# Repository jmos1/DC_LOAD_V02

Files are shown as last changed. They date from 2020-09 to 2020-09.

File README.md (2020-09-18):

# DC_LOAD_V02
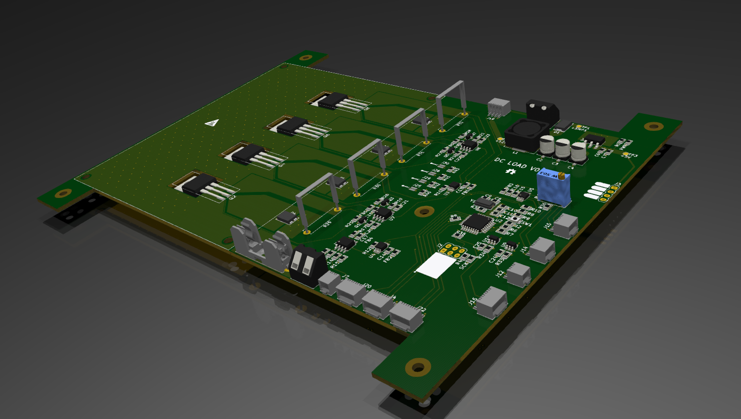
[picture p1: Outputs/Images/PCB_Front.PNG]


### Summary: ###
  This board is a follow up to the 1A DC_LOAD_V01 prototype. It is a 5A, 30V, 100W constant current load that will be mounted
  in a Jameco project enclosure. It currently isn't finished or tested yet, but feel free to have a look around anyway!
  
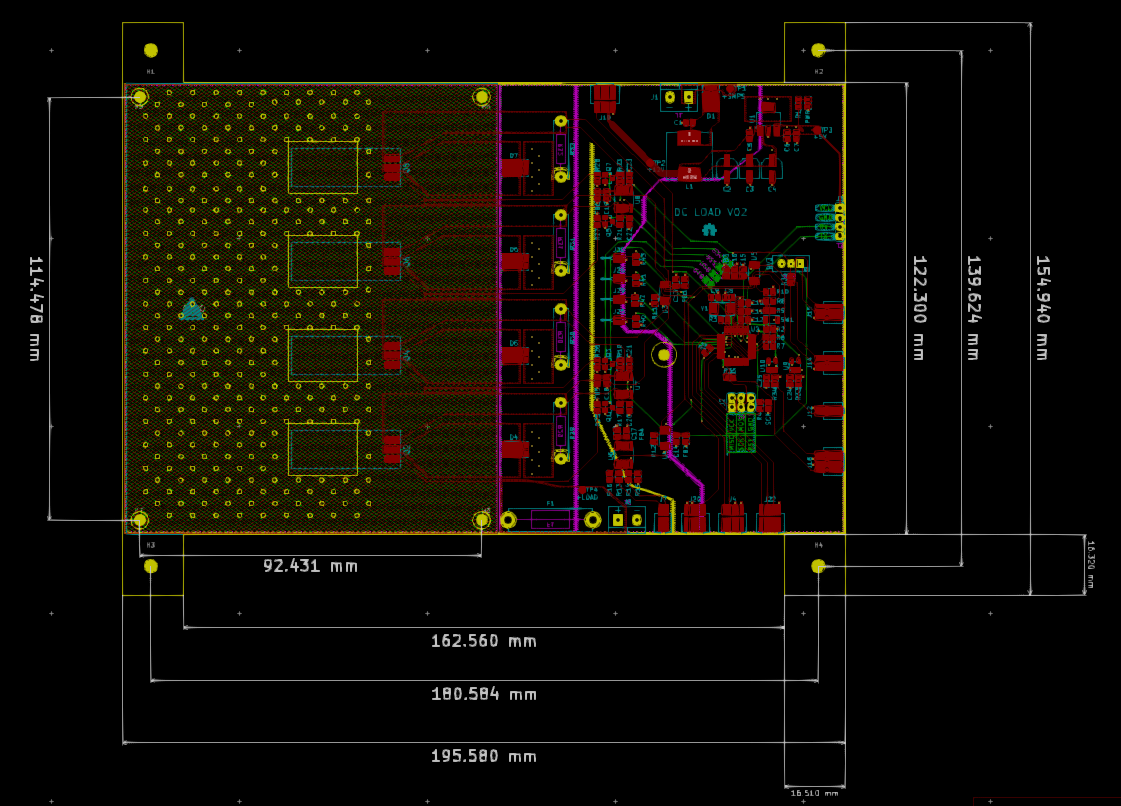
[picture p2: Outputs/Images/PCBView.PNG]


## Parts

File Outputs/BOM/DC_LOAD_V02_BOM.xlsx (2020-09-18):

Comment | MPN | Manufacturer | Part Number | Supplier | Quantity
IC INVERTER SCHMITT 1CH SOT23-5 | NC7S14M5X | ON Semiconductor | NC7S14M5XCT-ND | DigiKey | 2
IC ADC 16BIT SIGMA-DELTA 10VSSOP | ADS1115IDGSR | Texas Instruments | 296-38849-1-ND | DigiKey | 2
AC/DC CONVERTER 12V 16W | RS-15-12 | MEAN WELL USA Inc. | 1866-4128-ND | DigiKey | 1
IC OPAMP GP 2 CIRCUIT 8SOIC | LM358DR | Texas Instruments | 296-1014-1-ND | DigiKey | 2
TRANS NPN 40V 0.2A SOT23 | MMBT3904LT3G | ON Semiconductor | MMBT3904LT3GOSCT-ND | DigiKey | 4
FUSE CERM 5A 500VAC 400VDC 5X20 | 0477005.MXP | Littelfuse Inc. | F2990-ND | DigiKey | 1
IC DAC 12BIT V-OUT 10MSOP | MCP4728T-E/UN | Microchip Technology | MCP4728T-E/UNCT-ND | DigiKey | 1
PWR ENT MOD RCPT IEC320-C14 PNL | 1-1609112-1 | TE Connectivity Corcom Filters | CCM1914-ND | DigiKey | 1
FUSE BLOCK CART 250V 6.3A PCB | 3527 | Keystone Electronics | 36-3527-ND | DigiKey | 1
TERM BLK 2POS SIDE ENTRY 5MM PCB | 691137710002 | Würth Elektronik | 732-10955-ND | DigiKey | 2
IC REG LINEAR 5V 1.5A SOT223-4 | LM7805MPX/NOPB | Texas Instruments | 296-44518-1-ND | DigiKey | 1
MOSFET N-CH 55V 80A TO-220 | STP80NF55L-06 | STMicroelectronics | 497-5898-5-ND | DigiKey | 4
DIODE SCHOTTKY 100V 8A TO-277 | FSV8100V | ON Semiconductor | FSV8100VCT-ND | DigiKey | 5
THERMISTOR NTC 10KOHM 3380K BEAD | NXFT15XH103FA2B100 | Murata Electronics | 490-5630-ND | DigiKey | 4
IC OPAMP GP 2 CIRCUIT 8SOIC | LM6132BIMX/NOPB | Texas Instruments | LM6132BIMX/NOPB | DigiKey | 1
LED RED/YELLOW CLEAR 4SMD | APHB1608SYKSURKC | Kingbright | 754-1855-1-ND | DigiKey | 1
SWITCH ILLUMINATED PUSH | 54-701-R | NTE Electronics, Inc | 2368-54-701-R-ND | DigiKey | 1
SWITCH PUSH SPST-NO 3A 125V | PS1024ABLK | E-Switch | EG2011-ND | DigiKey | 1
BINDING POST BLACK 10 AMP | 81-BP6B | NTE Electronics, Inc | 2368-81-BP6B-ND | DigiKey | 1
BINDING POST RED 10 AMP | 81-BP6R | NTE Electronics, Inc | 2368-81-BP6R-ND | DigiKey | 1
FERRITE BEAD 300 OHM 0805 1LN | MI0805L301R-10 | Laird-Signal Integrity Products | 240-2391-1-ND | DigiKey | 6
CAP CER 10UF 25V X5R 0805 | GRM21BR61E106KA73K | Murata Electronics | 490-16824-1-ND | DigiKey | 6
CAP CER 1UF 50V X5R 0805 | GRM219R61H105KA73D | Murata Electronics | 490-10743-6-ND | DigiKey | 7
CAP CER 0.1UF 50V X7R 0805 | C0805C104M5RACTU | KEMET | 399-1169-1-ND | DigiKey | 5
CAP CER SMD 0805 .01UF X7R 5% 50 | C0805C103J5RAC7210 | KEMET | 399-17616-1-ND | DigiKey | 2
SWITCH TACTILE SPST-NO 0.02A 15V | EVP-AWED2A | Panasonic Electronic Components | P19745CT-ND | DigiKey | 1
LED GREEN CLEAR CHIP SMD | LTST-C171GKT | Lite-On Inc. | 160-1423-1-ND | DigiKey | 1
LED YELLOW CLEAR CHIP SMD | LTST-C171KSKT | Lite-On Inc. | 160-1428-1-ND | DigiKey | 1
RES 0.1 OHM 3W 1% RADIAL | MSR3-0R1F1 | Riedon | 696-1648-ND | DigiKey | 4
FIXED IND 100UH 1.6A 165 MOHM | 49101SC | Murata Power Solutions Inc. | 811-3615-1-ND | DigiKey | 1
CAP ALUM 22UF 20% 35V SMD | EEE-FK1V220R | Panasonic Electronic Components | PCE3838CT-ND | DigiKey | 3
CONN HEADER SMD R/A 2POS 1.5MM | 874380243 | Molex | WM7646CT-ND | DigiKey | 2
CONN HOUSING 2POS 1.5MM W/RAMP | 874390200 | Molex | WM2086-ND | DigiKey | 2
CONN HEADER SMD R/A 3POS 1.5MM | 874380343 | Molex | WM7647CT-ND | DigiKey | 2
CONN HOUSING 3POS 1.5MM W/RAMP | 874390300 | Molex | WM2087-ND | DigiKey | 2
CONN HEADER SMD R/A 4POS 1.5MM | 874380443 | Molex | WM7648CT-ND | DigiKey | 5
CONN HOUSING 4POS 1.5MM W/RAMP | 874390400 | Molex | WM2088-ND | DigiKey | 5
CRYSTAL 16.0000MHZ 18PF SMD | ABM7-16.000MHZ-D2Y-T | Abracon LLC | 535-9840-1-ND | DigiKey | 1
CAP CER 18PF 50V C0G/NP0 0805 | C0805C180K5GACTU | KEMET | 399-8030-1-ND | DigiKey | 2
RES 0 OHM JUMPER 1/8W 0805 | RMCF0805ZT0R00 | Stackpole Electronics Inc | RMCF0805ZT0R00CT-ND | DigiKey | 4
RES SMD 1M OHM 1% 1/8W 0805 | RC0805FR-071ML | Yageo | 311-1.00MCRCT-ND | DigiKey | 1
RES 1K OHM 1% 1/4W 0805 | RNCP0805FTD1K00 | Stackpole Electronics Inc | RNCP0805FTD1K00CT-ND | DigiKey | 19
RES SMD 10K OHM 1% 1/8W 0805 | RC0805FR-0710KL | Yageo | 311-10.0KCRCT-ND | DigiKey | 13
RES 100K OHM 0.05% 1/8W 0805 | ERA-6ARW104V | Panasonic Electronic Components | P100KBSCT-ND | DigiKey | 2
RES 10K OHM 0.05% 1/8W 0805 | ERA-6ARW103V | Panasonic Electronic Components | P10KBSCT-ND | DigiKey | 2
IC MCU 8BIT 32KB FLASH 32TQFP | ATMEGA328PB-AUR | Microchip Technology | ATMEGA328PB-AURCT-ND | DigiKey | 1

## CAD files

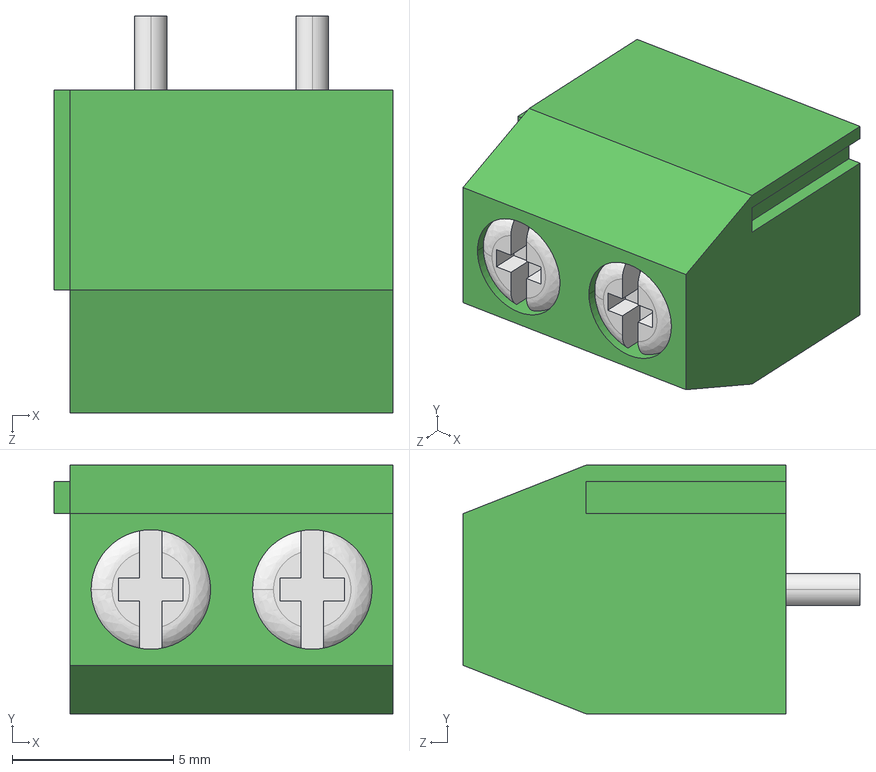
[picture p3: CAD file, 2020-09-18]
3D Models/TERM_BLK_1x2_691137710002.step
10.5 x 7.70 x 12.3 mm

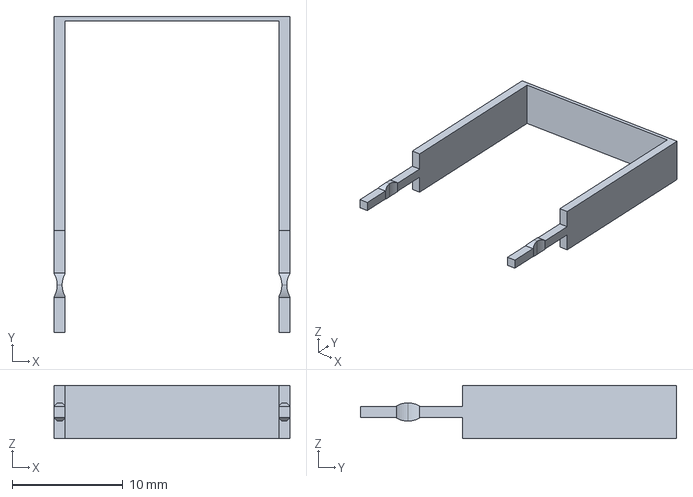
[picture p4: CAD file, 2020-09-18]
3D Models/RSHUNT_MSR3-0R1F1.stp
21.3 x 28.6 x 4.80 mm

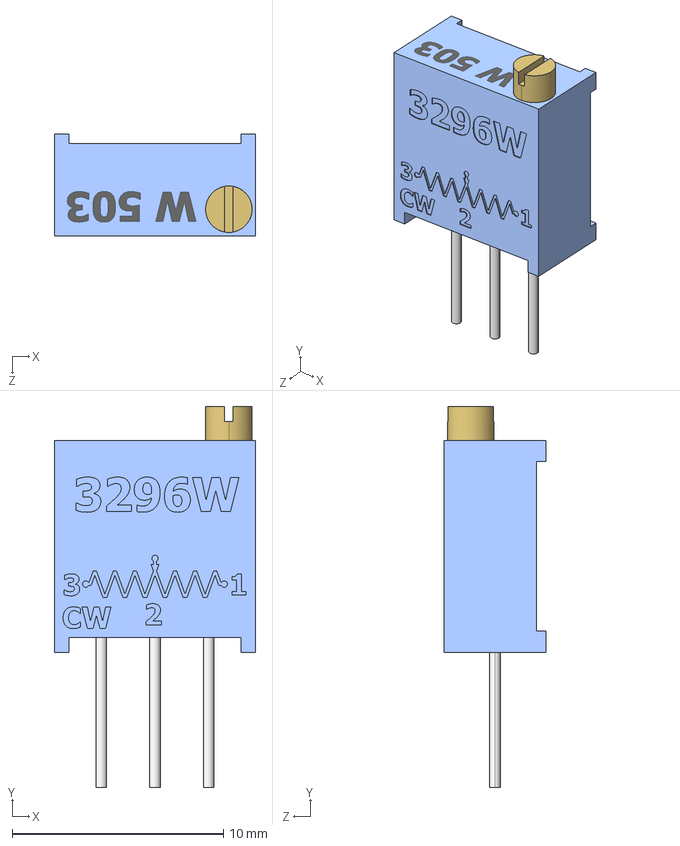
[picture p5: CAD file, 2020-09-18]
3D Models/TRIM_POT_50K.STEP
9.53 x 18.0 x 4.83 mm

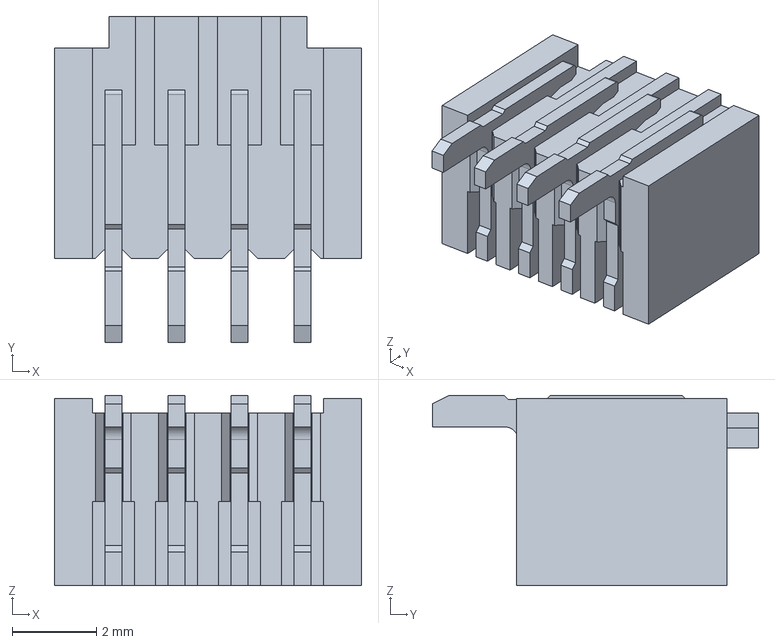
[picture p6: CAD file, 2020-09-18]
3D Models/MOLEX_1x4_CONN_0874380443.stp
7.30 x 7.75 x 4.52 mm

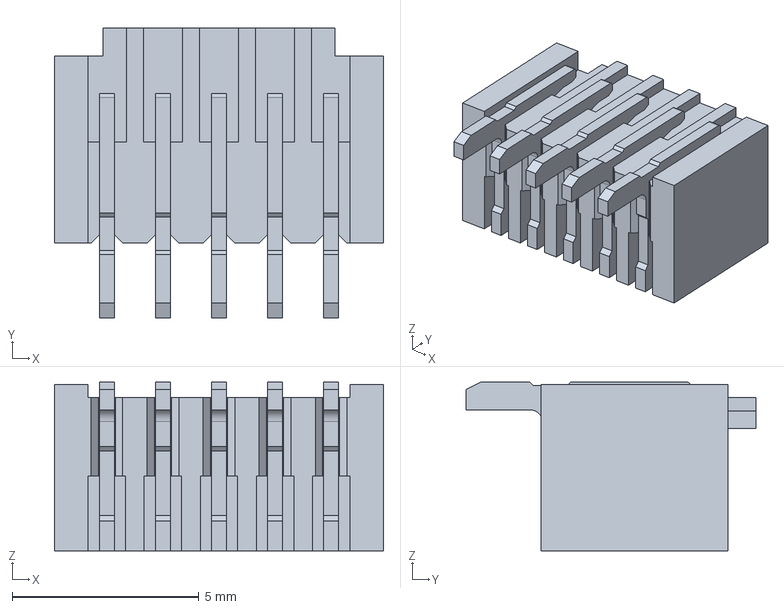
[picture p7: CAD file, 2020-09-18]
3D Models/MOLEX_1x5_CONN_874380543.stp
8.80 x 7.75 x 4.52 mm

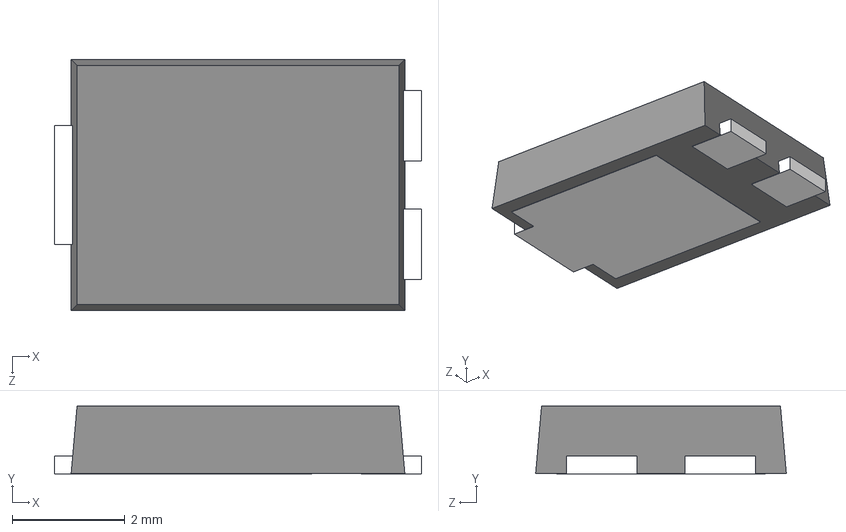
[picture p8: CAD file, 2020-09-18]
3D Models/POWER_DIODE_FSV12100V.STEP
6.50 x 1.20 x 4.44 mm

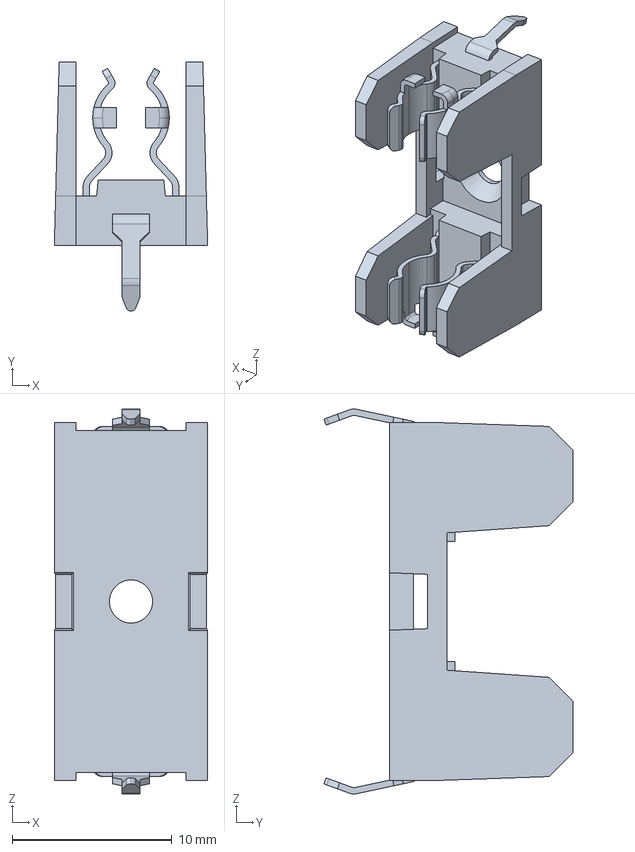
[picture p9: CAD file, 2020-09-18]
3D Models/FUSE_CLIP_3527.stp
9.60 x 15.6 x 24.1 mm

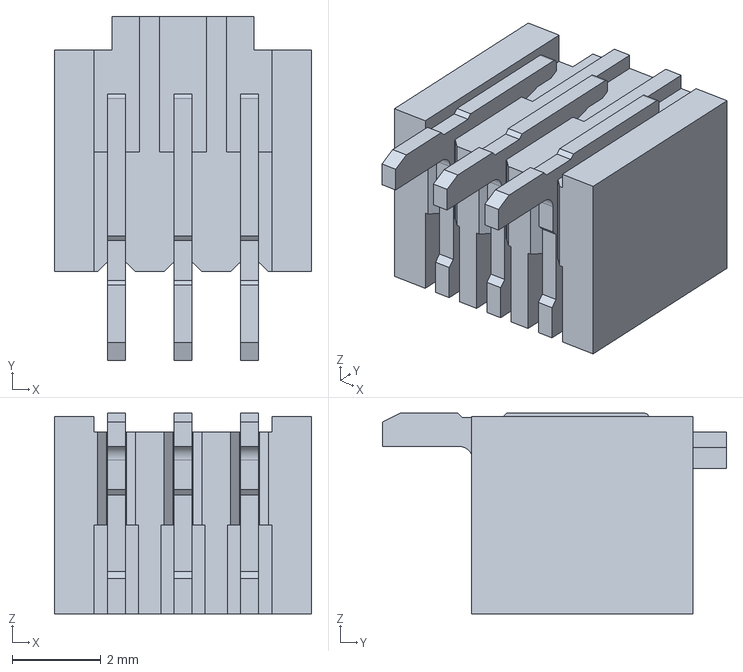
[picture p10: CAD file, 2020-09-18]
3D Models/MOLEX_1x3_CONN_874380343.stp
5.80 x 7.75 x 4.52 mm

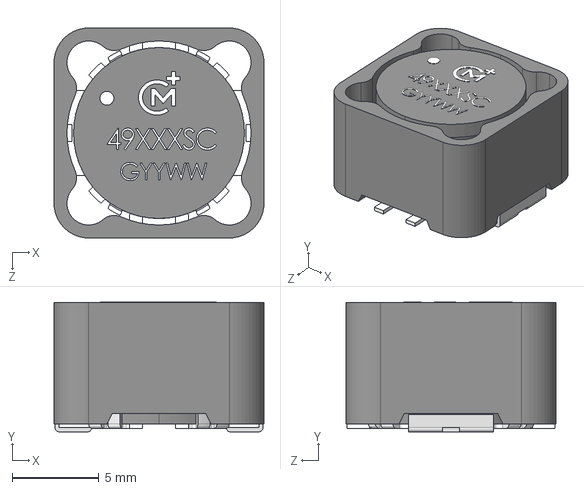
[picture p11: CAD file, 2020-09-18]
3D Models/INDUCTOR_100U_‎49101SC‎.STEP
12.1 x 7.47 x 12.1 mm

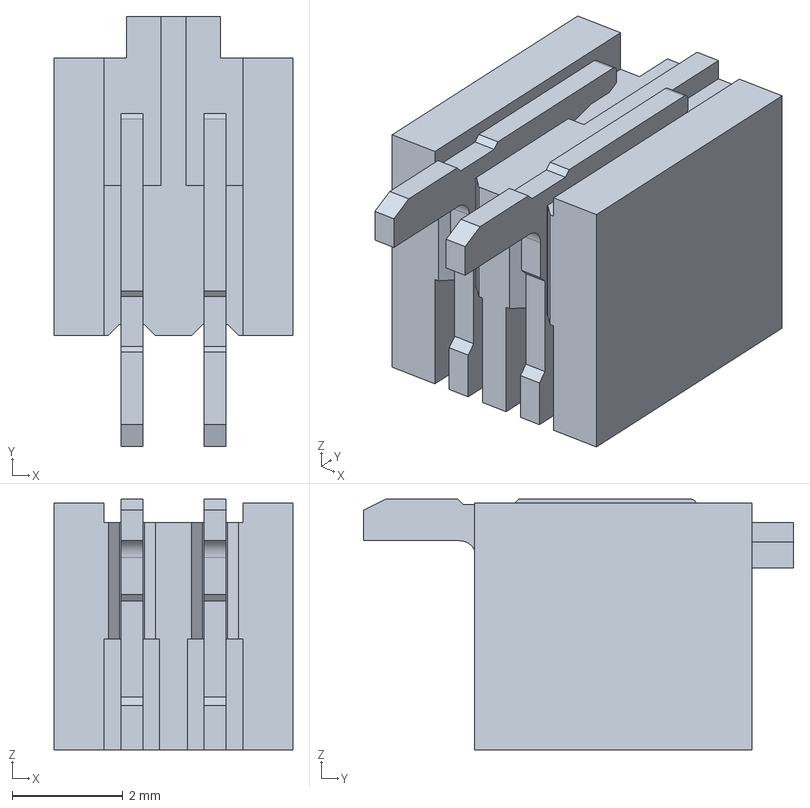
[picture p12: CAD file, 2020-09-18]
3D Models/MOLEX_1x2_CONN_874380243.stp
4.30 x 7.75 x 4.52 mm

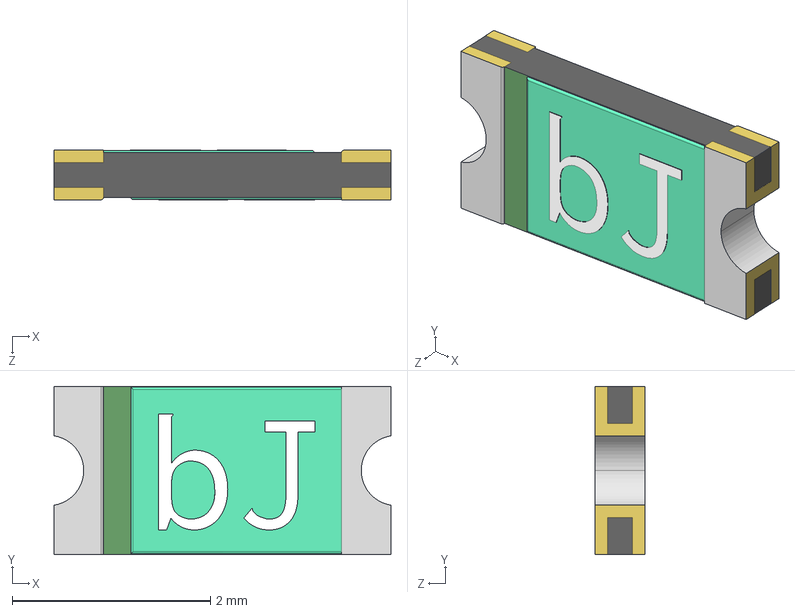
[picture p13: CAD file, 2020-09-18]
3D Models/FUSE_375MA_0466.375NR.STEP
3.40 x 1.70 x 0.508 mm

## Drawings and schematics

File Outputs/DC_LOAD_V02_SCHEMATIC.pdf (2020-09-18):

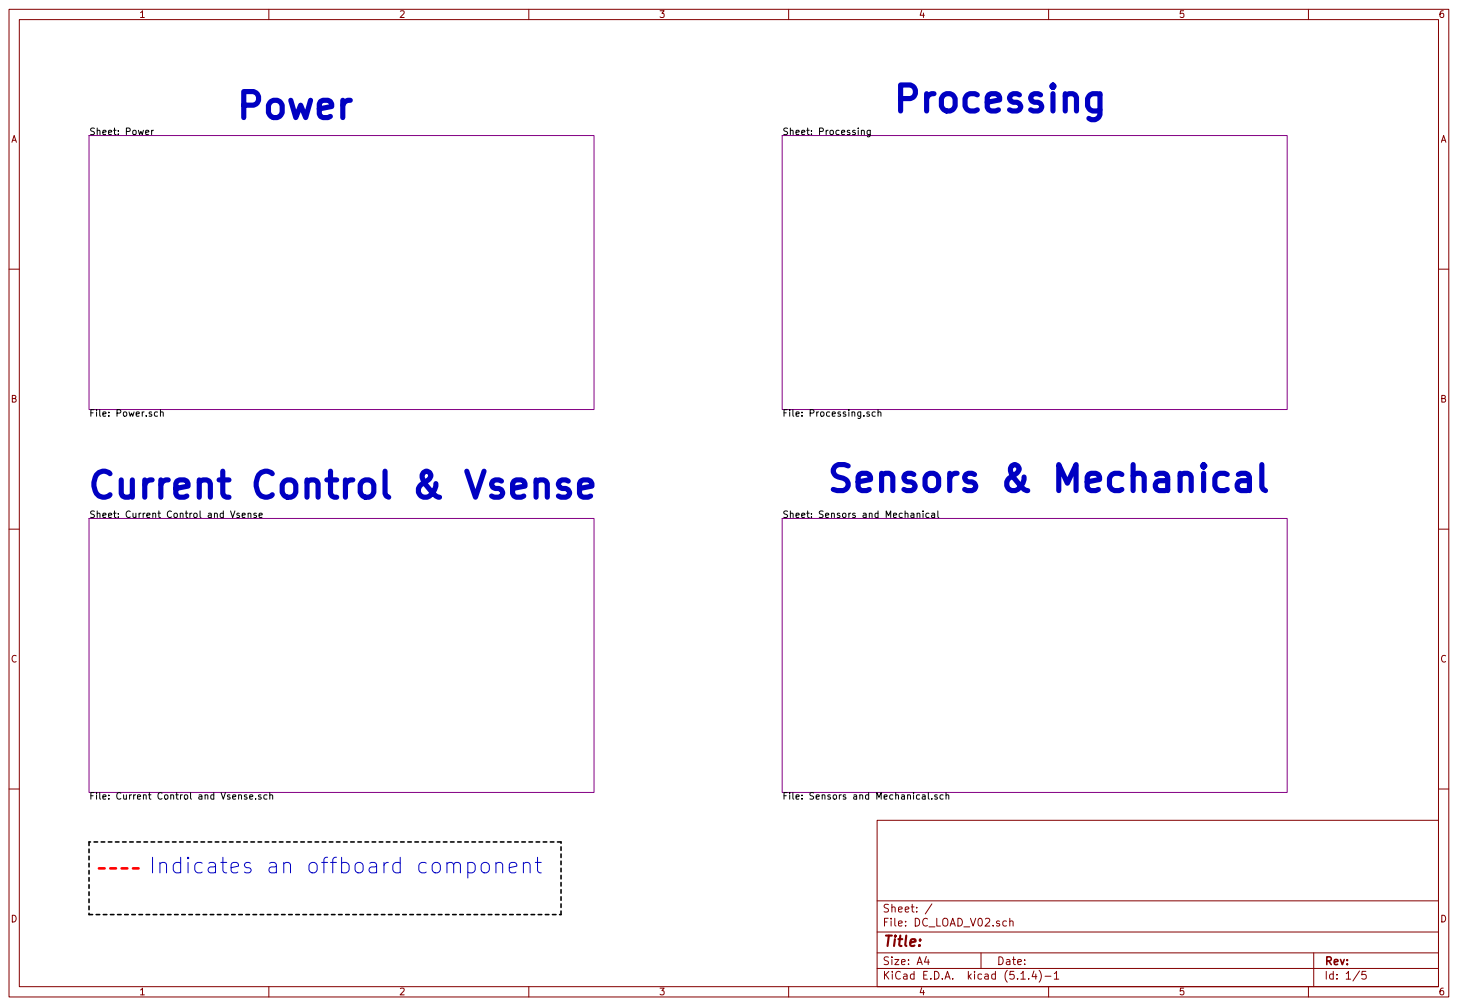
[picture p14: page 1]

Indicates an offboard component

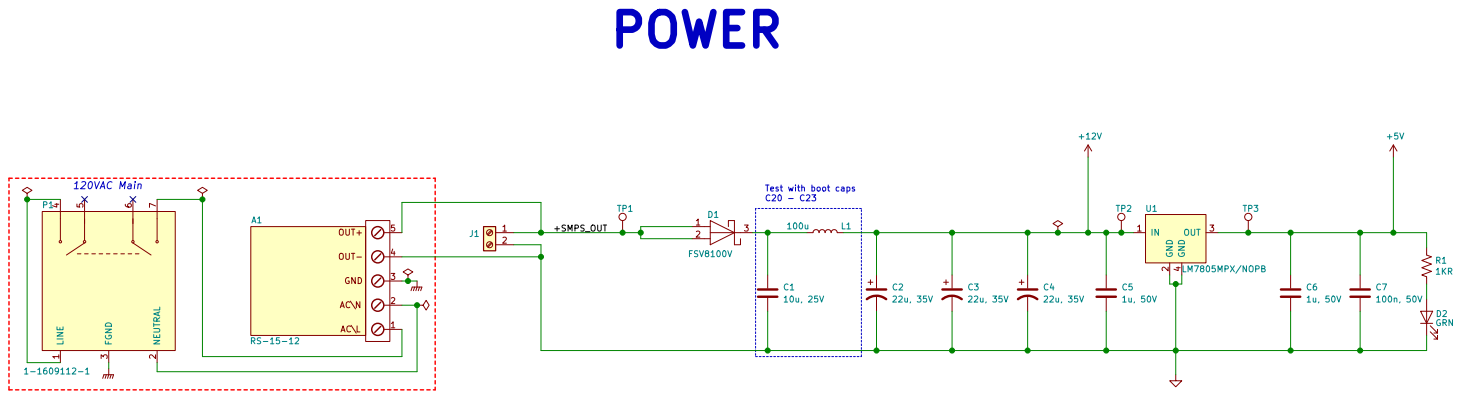
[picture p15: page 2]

Test with boot caps C20 - C23 POWER

AC\L GND OUT+ OUT- AC\N

Id: 2/5 Title: Power File: Power.sch Sheet: /Power/

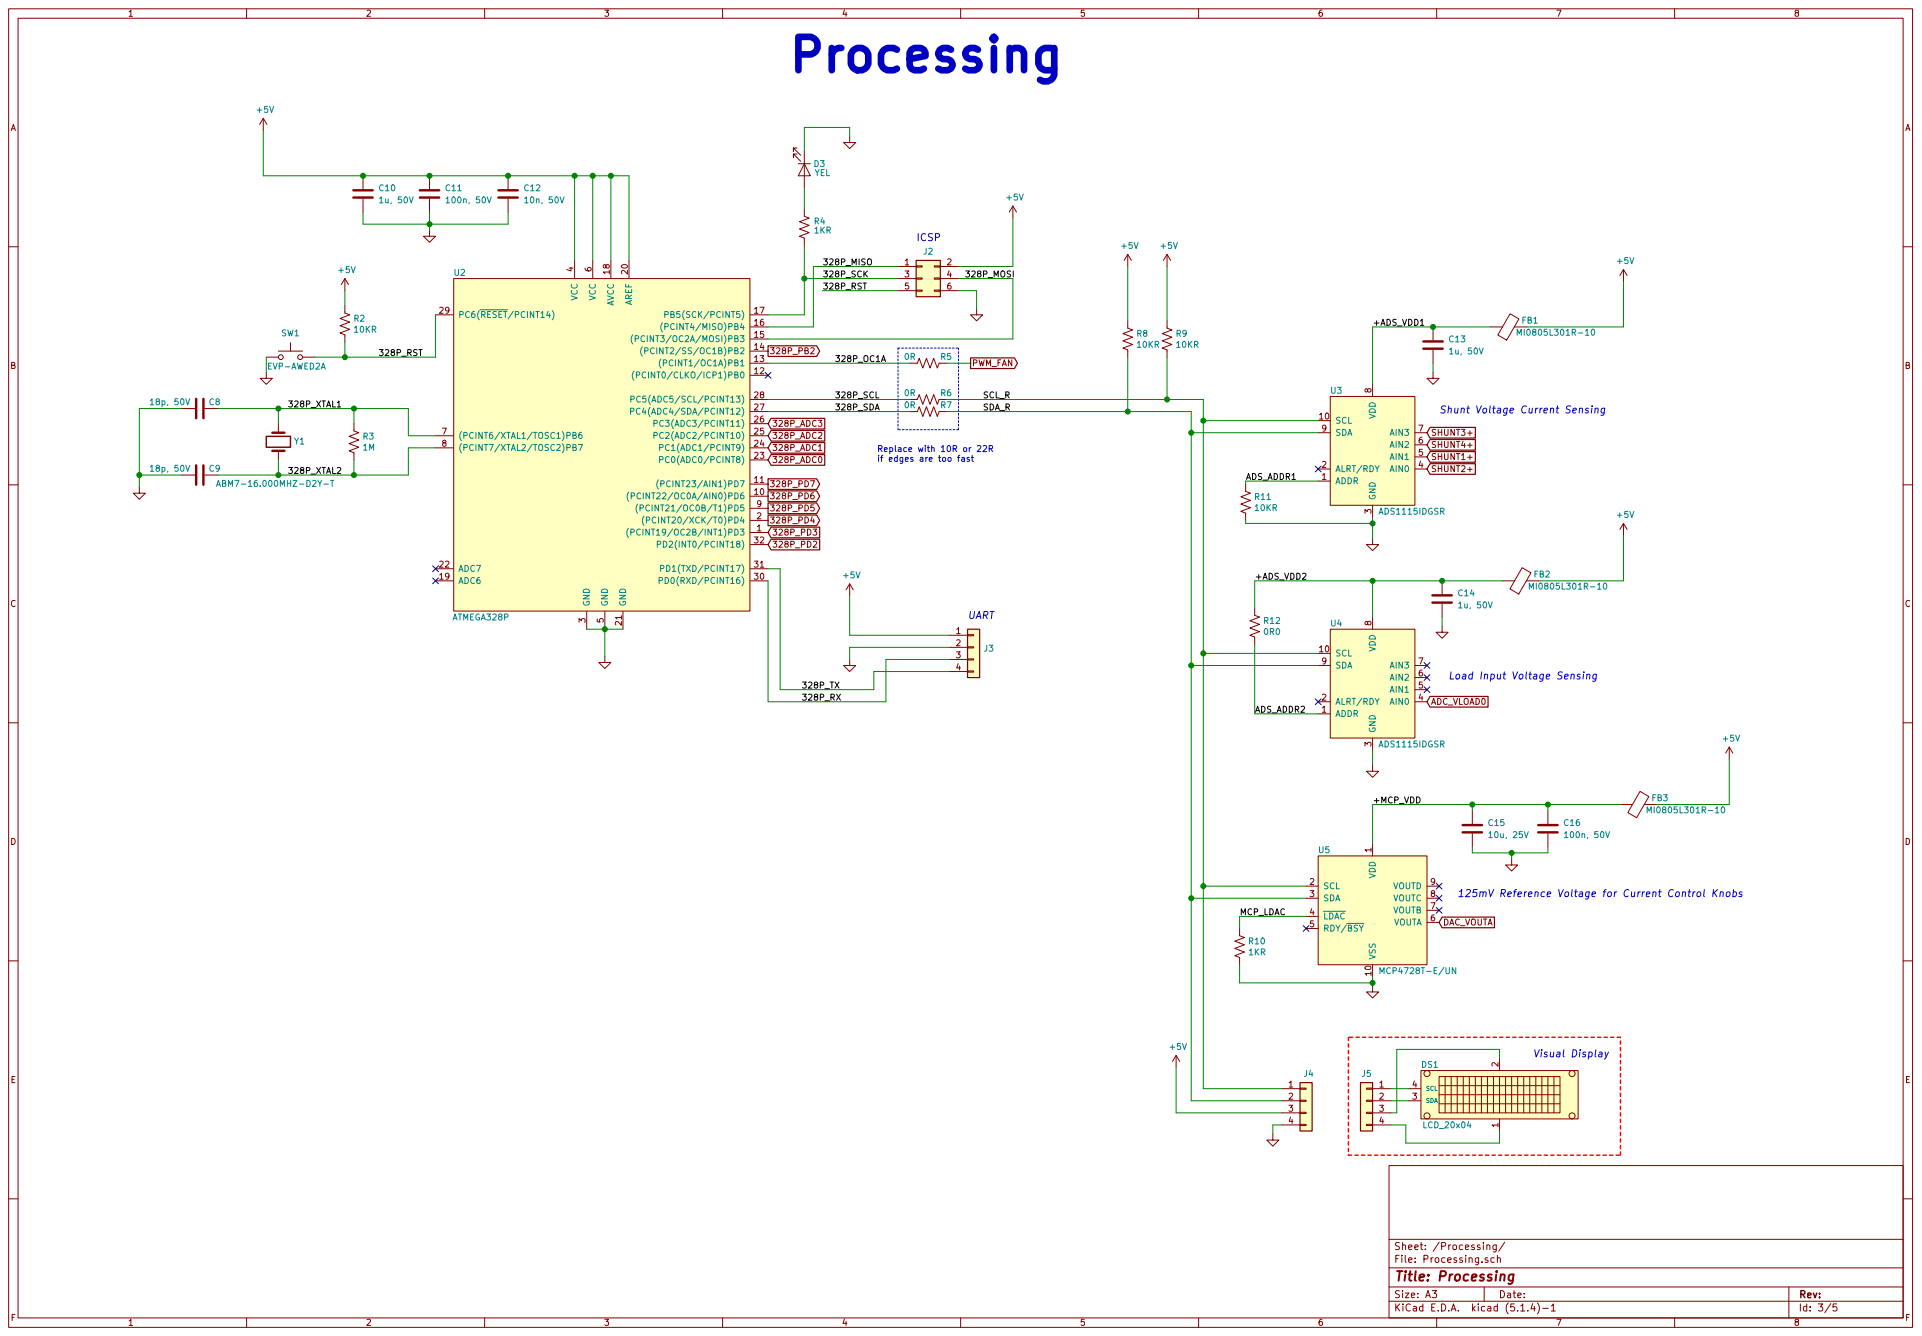
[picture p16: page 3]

Shunt Voltage Current Sensing

Replace with 10R or 22R
if edges are too fast

Load Input Voltage Sensing

125mV Reference Voltage for Current Control Knobs

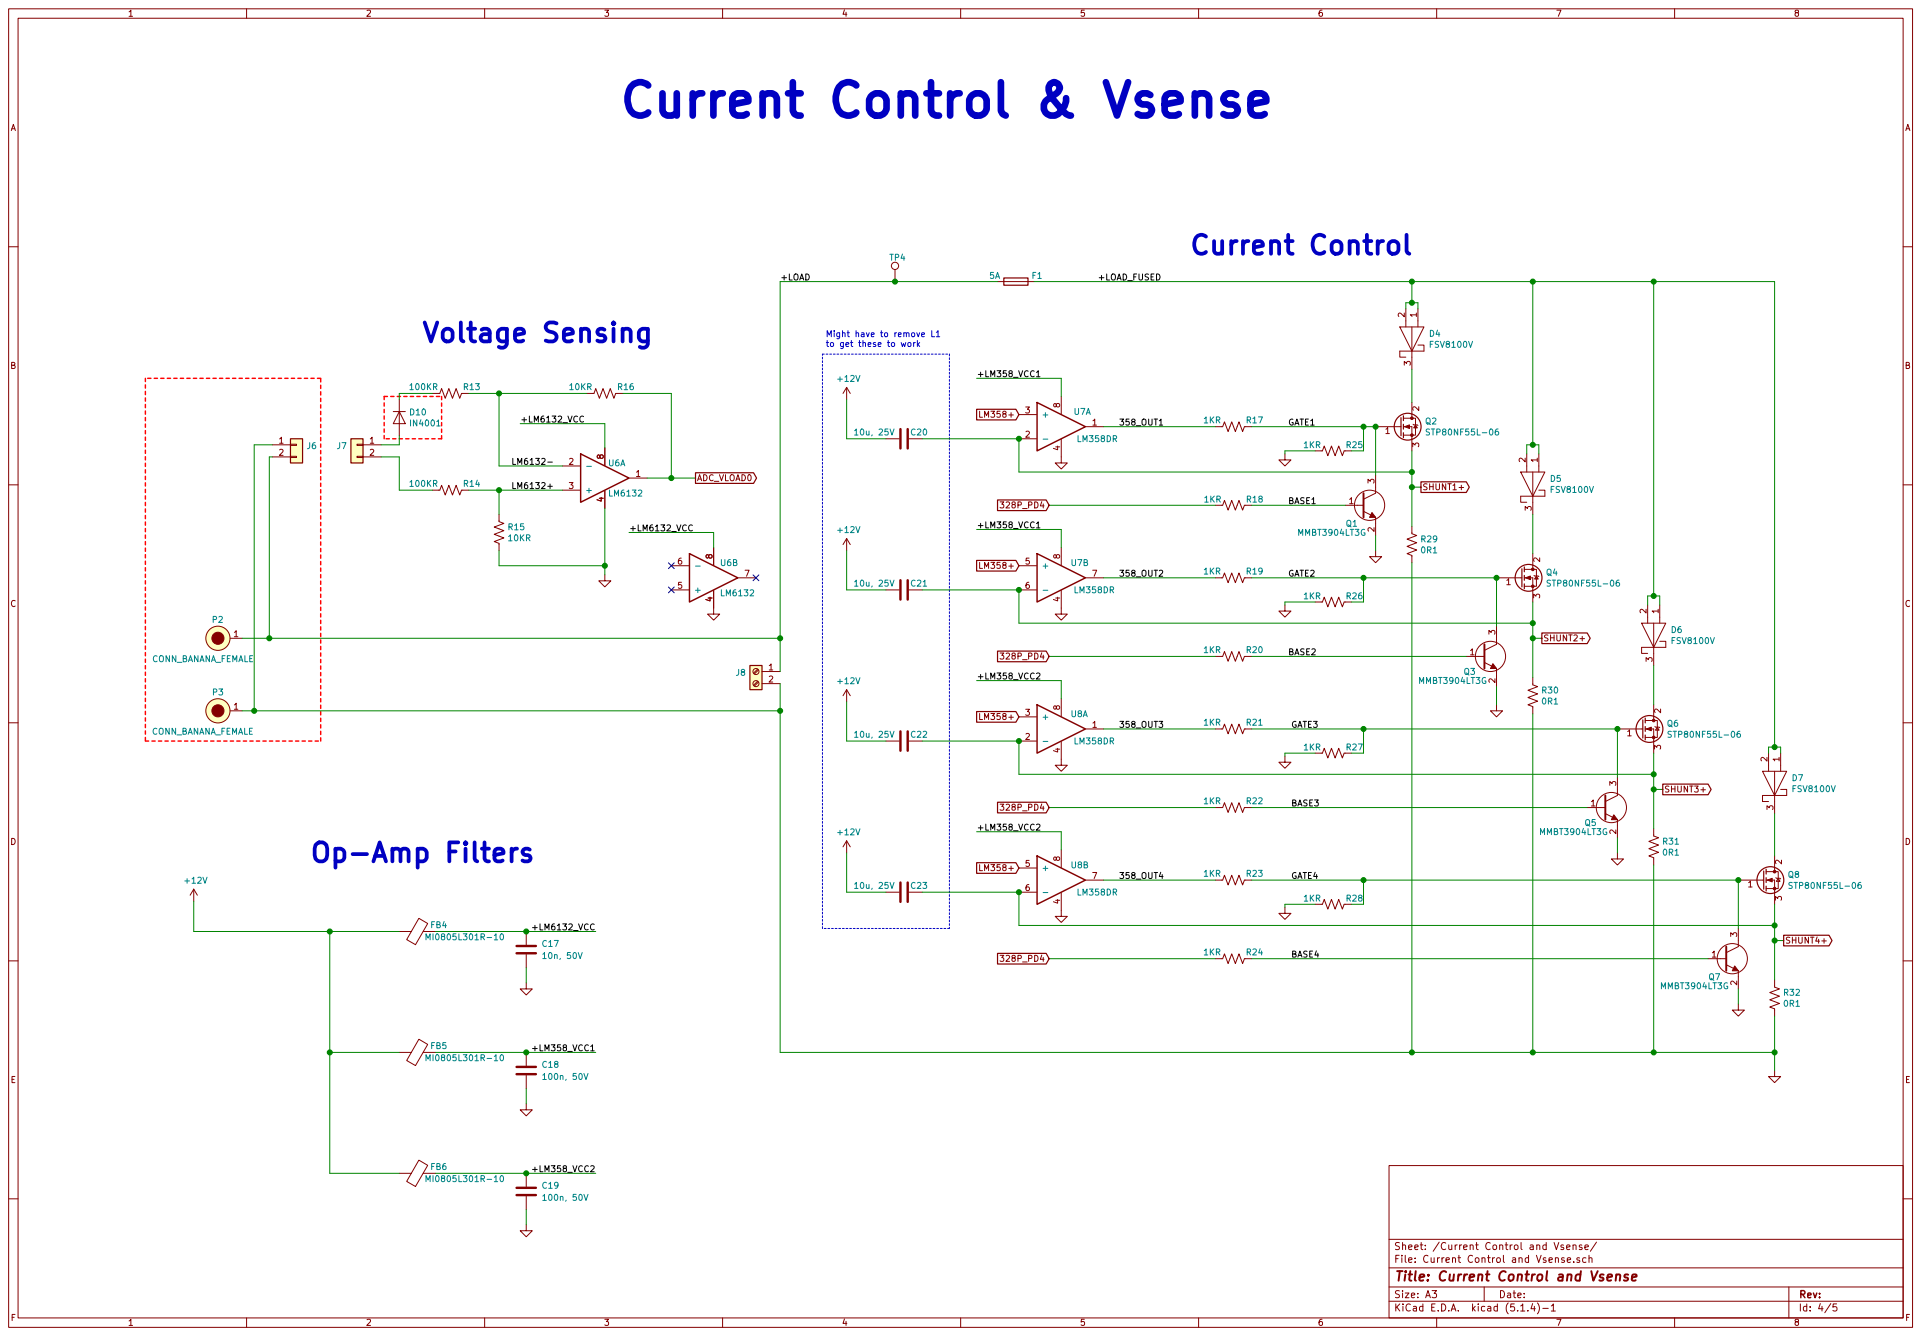
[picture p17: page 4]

Might have to remove L1
to get these to work

File: Current Control and Vsense.sch Sheet: /Current Control and Vsense/
Id: 4/5 Title: Current Control and Vsense

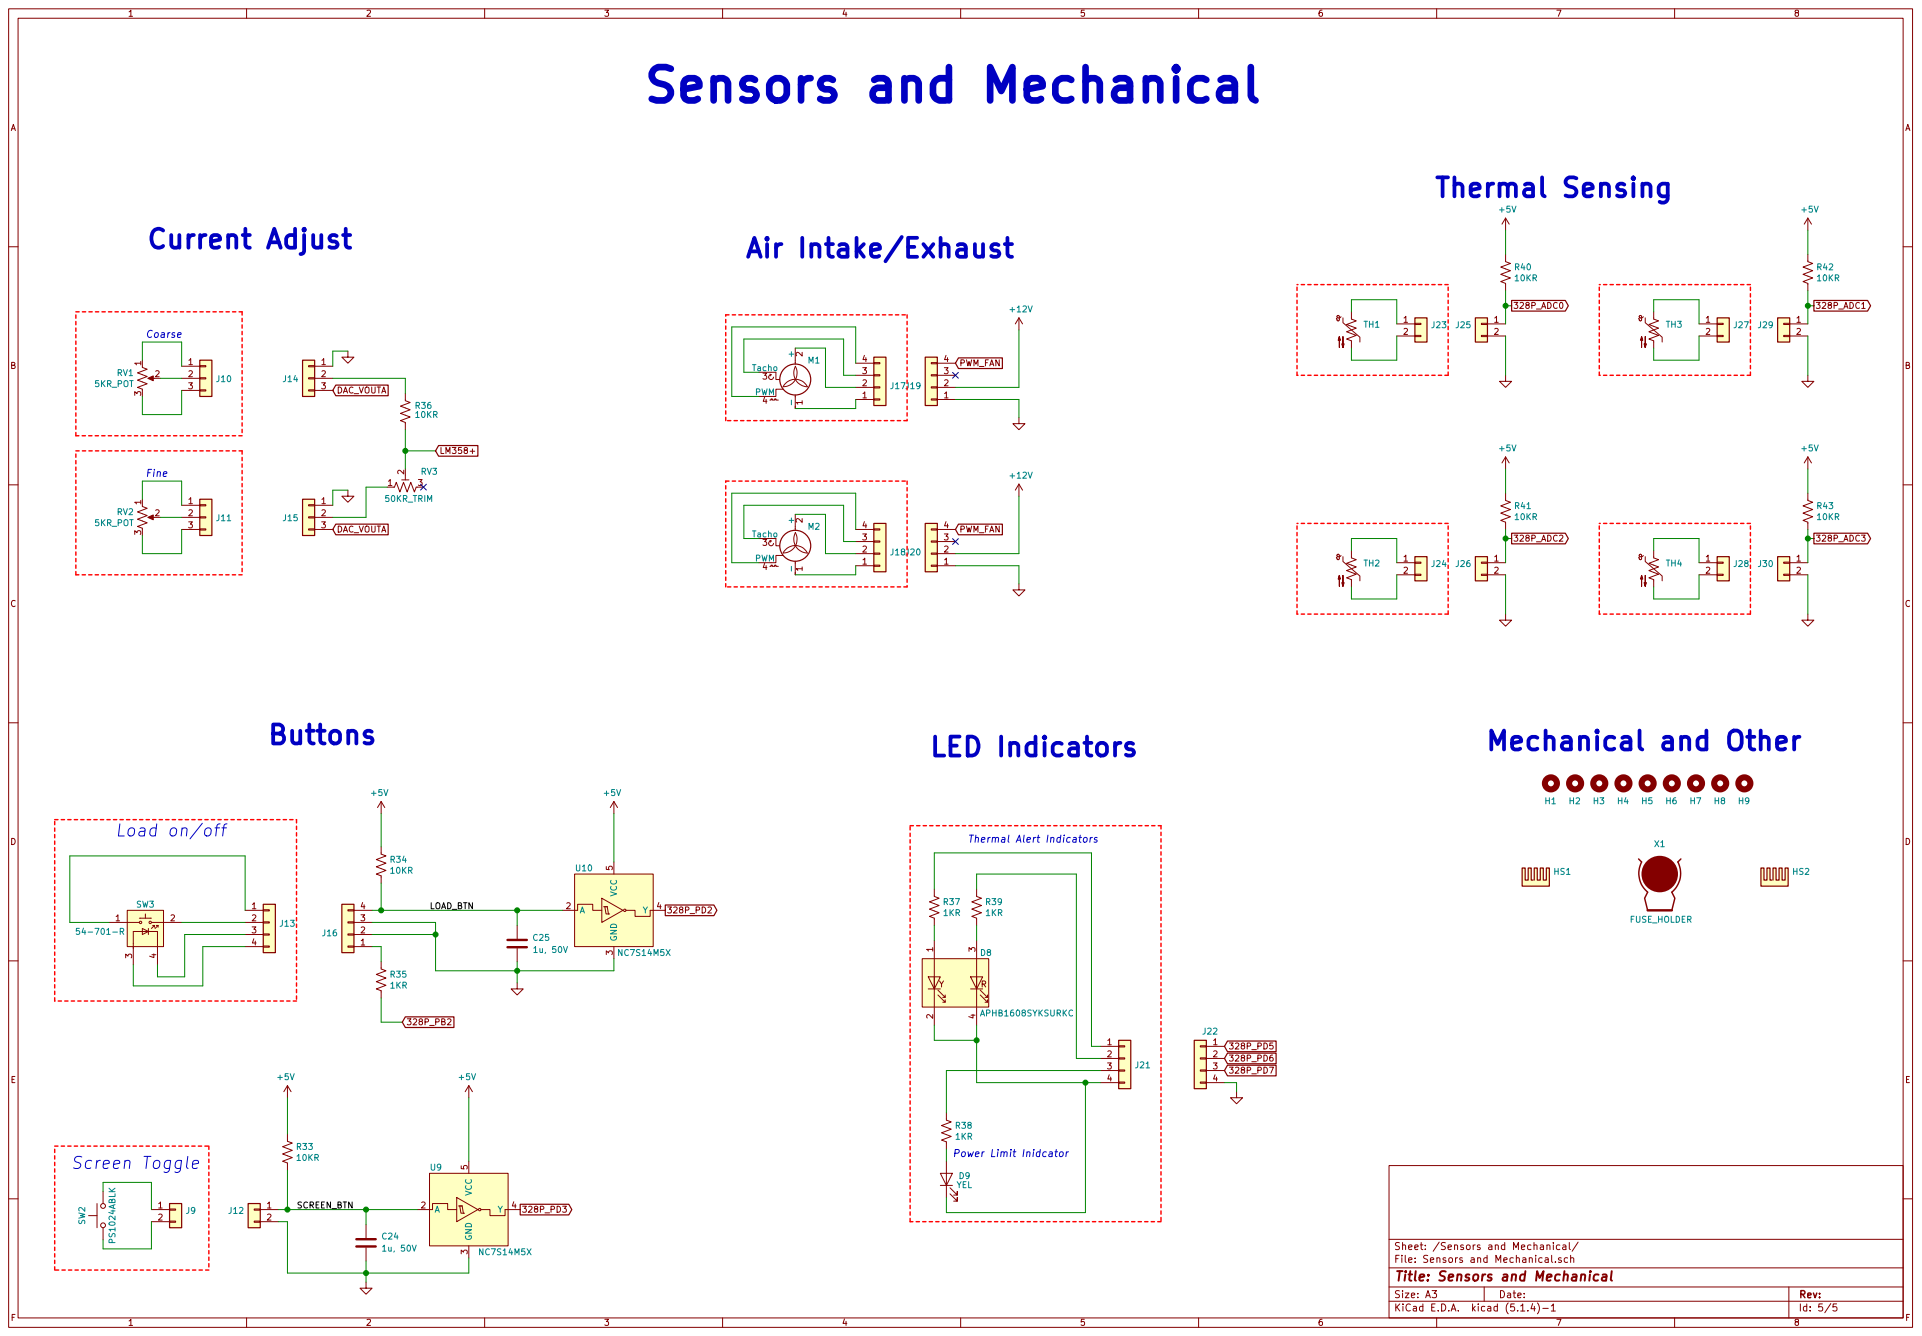
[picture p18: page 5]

Thermal Alert Indicators Screen Toggle

Id: 5/5 Title: Sensors and Mechanical File: Sensors and Mechanical.sch Sheet: /Sensors and Mechanical/

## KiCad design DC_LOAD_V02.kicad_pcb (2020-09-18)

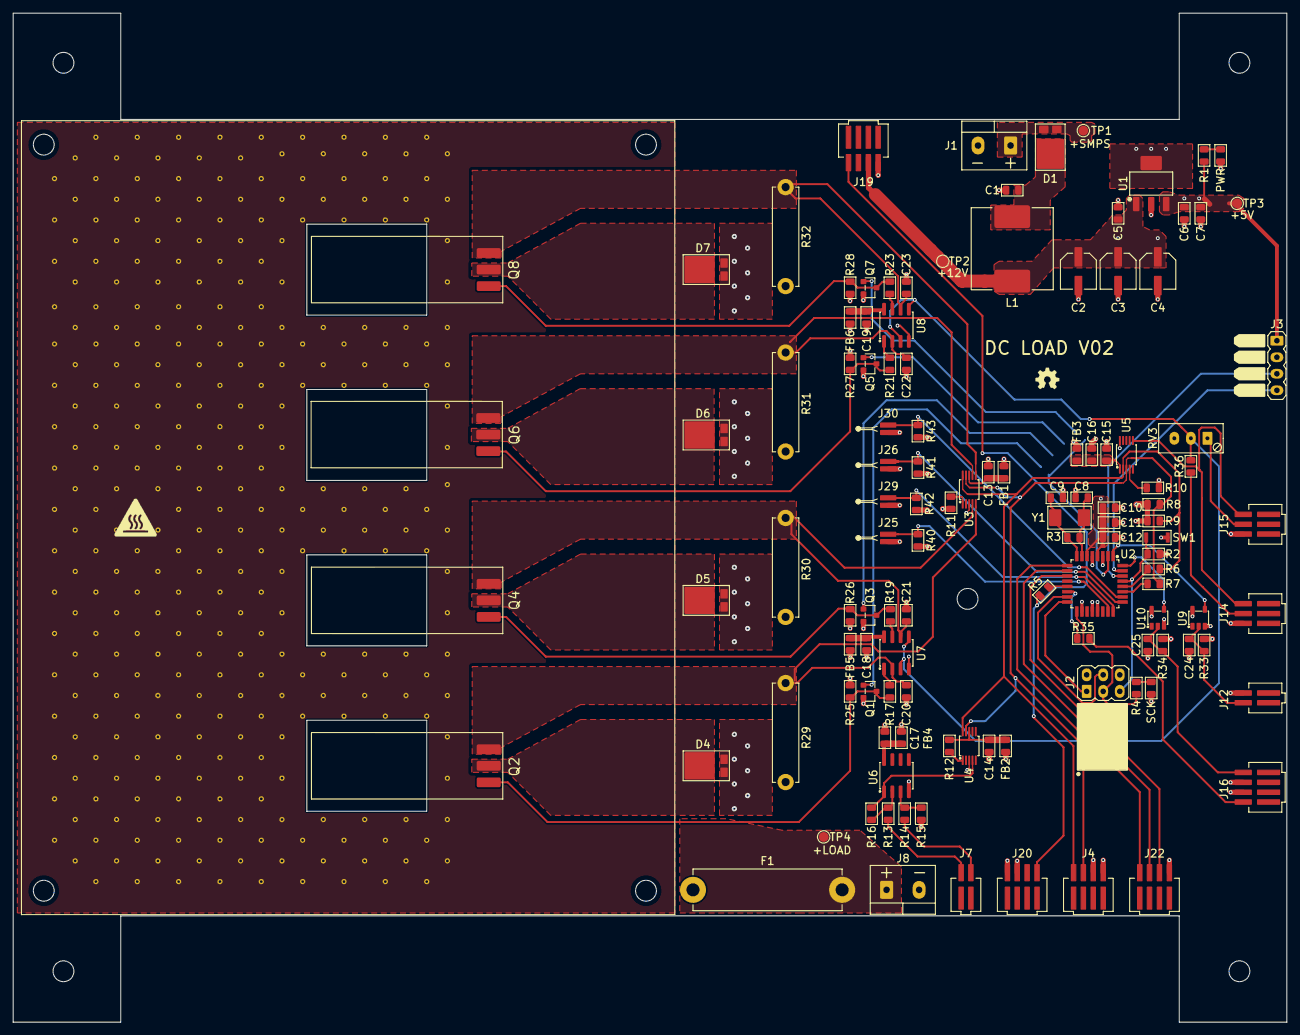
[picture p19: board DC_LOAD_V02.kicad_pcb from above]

Board: 4 copper layers, 195.6 x 154.9 mm, 131 parts (0 on the bottom side), 75 nets.

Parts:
C1, C15, C20, C21, C22, C23: 10u, 25V; 0805_2012Metric_Reflow
C2, C3, C4: 22u, 35V; CP_Elec_5x5.8
C5, C6, C10, C13, C14, C24, C25: 1u, 50V; 0805_2012Metric_Reflow
C7, C11, C16, C18, C19: 100n, 50V; 0805_2012Metric_Reflow
C8, C9: 18p, 50V; 0805_2012Metric_Reflow
C12, C17: 10n, 50V; 0805_2012Metric_Reflow
D1, D4, D5, D6, D7: FSV8100V
F1: 5A; Fuse_Holder_5x20mm_3527
FB1, FB2, FB3, FB4, FB5, FB6: MI0805L301R-10; 0805_2012Metric_Reflow
H1, H2, H3, H4, H5, H6, H7, H8, H9: MountingHole; MountingHole_3.2mm_M3
J1, J8: Screw_Terminal_01x02; Conn_Term_2POS_5mm_PITCH_691137710002
J2: Conn_02x03_Odd_Even; Conn_Header_Male_2x3_2.54mm_PITCH
J3: Conn_01x04; Conn_Header_Male_1x4_2.54mm_PITCH
J4, J16, J19, J20, J22: Conn_01x04; Conn_Molex_1x4_Horizontal_1.5mm_Pitch_0874380443
J7, J12: Conn_01x02; Conn_Molex_1x2_Horizontal_1.5mm_Pitch_0874380243
J14, J15: Conn_01x03; Conn_Molex_1x3_Horizontal_1.5mm_Pitch_0874380343
J25, J26, J29, J30: Conn_01x02; Therm_Pad
L1: 100u; 49101SC
PWR: GRN; 0805_2012Metric_Reflow
Q1, Q3, Q5, Q7: MMBT3904LT3G; SOT-23
Q2, Q4, Q6, Q8: STP80NF55L-06
R1, R4, R10, R17, R18, R19, R20, R21, R22, R23, R24, R25, R26, R27, R28, R35: 1KR; 0805_2012Metric_Reflow
R2, R8, R9, R11, R15, R16, R33, R34, R36, R40, R41, R42, R43: 10KR; 0805_2012Metric_Reflow
R3: 1M; 0805_2012Metric_Reflow
R5, R6, R7: 0R; 0805_2012Metric_Reflow
R12: 0R0; 0805_2012Metric_Reflow
R13, R14: 100KR; 0805_2012Metric_Reflow
R29, R30, R31, R32: 0R1; R_Radial_0R1_Riedon_MSR3
RV3: 50KR_TRIM; Pot_Trim_THT_9.5mmx4.35mm
SCK: YEL; 0805_2012Metric_Reflow
SW1: EVP-AWED2A
TP1, TP2, TP3, TP4: TestPoint; TestPoint_Pad_D1.5mm
U1: LM7805MPX/NOPB; SOT-223
U2: ATMEGA328P; TQFP-32_7x7mm_P0.8mm
U3, U4: ADS1115IDGSR; VSSOP-10_.5mm_PITCH_3x3mm_PKG
U5: MCP4728T-E/UN; MSOP-10_3x3mm_P0.5mm
U6: LM6132; SOIC-8_3.9x4.9mm_P1.27mm
U7, U8: LM358DR; SOIC-8_3.9x4.9mm_P1.27mm
U9, U10: NC7S14M5X; SOT-23-5
Y1: ABM7-16.000MHZ-D2Y-T

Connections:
328P_ADC0: J25.1, R40.2, U2.23
328P_ADC1: J29.1, R42.2, U2.24
328P_ADC2: J26.1, R41.2, U2.25
328P_ADC3: J30.1, R43.2, U2.26
328P_PB2: R35.2, U2.14
328P_PD2: U2.32, U10.4
328P_PD3: U2.1, U9.4
328P_PD4: R18.2, R20.1, R22.1, R24.1, U2.2
328P_PD5: J22.1, U2.9
328P_PD6: J22.2, U2.10
328P_PD7: J22.3, U2.11
+5V: C6.1, C7.1, C10.1, C11.1, C12.1, FB1.2, FB2.2, FB3.2, J2.2, J3.1, J4.3, R1.1, R2.1, R8.1, R9.1, R33.1, R34.1, R40.1, R41.1, R42.1, R43.1, TP3.1, U1.3, U2.4, U2.6, U2.18, U2.20, U9.5, U10.5
+12V: C2.1, C3.1, C4.1, C5.1, C20.1, C21.1, C22.1, C23.1, FB4.1, FB5.1, FB6.1, J19.2, J20.2, L1.2, TP2.1, U1.1
/Current Control and Vsense/358_OUT1: R17.1, U7.1
/Current Control and Vsense/358_OUT2: R19.1, U7.7
/Current Control and Vsense/358_OUT3: R21.1, U8.1
/Current Control and Vsense/358_OUT4: R23.1, U8.7
/Current Control and Vsense/+LM358_VCC1: C18.1, FB5.2, U7.8
/Current Control and Vsense/+LM358_VCC2: C19.1, FB6.2, U8.8
/Current Control and Vsense/+LM6132_VCC: C17.1, FB4.2, U6.8
/Current Control and Vsense/+LOAD: F1.2, J8.1, TP4.1
/Current Control and Vsense/+LOAD_FUSED: D4.1, D4.2, D5.1, D5.2, D6.1, D6.2, D7.1, D7.2, F1.1
/Current Control and Vsense/BASE1: Q1.1, R18.1
/Current Control and Vsense/BASE2: Q3.1, R20.2
/Current Control and Vsense/BASE3: Q5.1, R22.2
/Current Control and Vsense/BASE4: Q7.1, R24.2
/Current Control and Vsense/GATE1: Q1.3, Q2.1, R17.2, R25.1
/Current Control and Vsense/GATE2: Q3.3, Q4.1, R19.2, R26.1
/Current Control and Vsense/GATE3: Q5.3, Q6.1, R21.2, R27.1
/Current Control and Vsense/GATE4: Q7.3, Q8.1, R23.2, R28.1
/Current Control and Vsense/LM6132+: R14.2, R15.1, U6.3
/Current Control and Vsense/LM6132-: R13.2, R16.1, U6.2
/Power/+SMPS_OUT: D1.1, D1.2, J1.1, TP1.1
/Processing/328P_MISO: J2.1, U2.16
/Processing/328P_MOSI: J2.4, U2.15
/Processing/328P_OC1A: R5.1, U2.13
/Processing/328P_RST: J2.5, R2.2, SW1.2, U2.29
/Processing/328P_RX: J3.3, U2.30
/Processing/328P_SCK: J2.3, R4.2, U2.17
/Processing/328P_SCL: R6.1, U2.28
/Processing/328P_SDA: R7.1, U2.27
/Processing/328P_TX: J3.4, U2.31
/Processing/328P_XTAL1: C8.2, R3.1, U2.7, Y1.2
/Processing/328P_XTAL2: C9.2, R3.2, U2.8, Y1.1
/Processing/+ADS_VDD1: C13.1, FB1.1, U3.8
/Processing/+ADS_VDD2: C14.1, FB2.1, R12.1, U4.8
/Processing/+MCP_VDD: C15.1, C16.1, FB3.1, U5.1
/Processing/ADS_ADDR1: R11.1, U3.1
/Processing/ADS_ADDR2: R12.2, U4.1
/Processing/MCP_LDAC: R10.1, U5.4
/Processing/SCL_R: J4.1, R6.2, R9.2, U3.10, U4.10, U5.2
/Processing/SDA_R: J4.2, R7.2, R8.2, U3.9, U4.9, U5.3
/Sensors and Mechanical/LOAD_BTN: C25.1, J16.4, R34.2, U10.2
/Sensors and Mechanical/SCREEN_BTN: C24.2, J12.1, R33.2, U9.2
ADC_VLOAD0: R16.2, U4.4, U6.1
DAC_VOUTA: J14.3, J15.3, U5.6
GND: C1.2, C2.2, C3.2, C4.2, C5.2, C6.2, C7.2, C8.1, C9.1, C10.2, C11.2, C12.2, C13.2, C14.2, C15.2, C16.2, C17.2, C18.2, C19.2, C24.1, C25.2, J1.2, J2.6, J3.2, J4.4, J8.2, J12.2, J14.1, J15.1, J16.2, J16.3, J19.1, J20.1, J22.4, J25.2, J26.2, J29.2, J30.2, PWR.1, Q1.2, Q3.2, Q5.2, Q7.2, R10.2, R11.2, R15.2, R25.2, R26.2, R27.2, R28.2, R29.2, R30.2, R31.2, R32.2, SCK.1, SW1.1, U1.2, U1.4, U2.3, U2.5, U2.21, U3.3, U4.3, U5.10, U6.4, U7.4, U8.4, U9.3, U10.3
LM358+: R36.2, RV3.2, U7.3, U7.5, U8.3, U8.5
unnamed: C1.1, D1.3, L1.1
unnamed: PWR.2, R1.2
unnamed: R4.1, SCK.2
unnamed: D4.3, Q2.2
unnamed: D5.3, Q4.2
unnamed: D6.3, Q6.2
unnamed: D7.3, Q8.2
unnamed: J7.1, R13.1
unnamed: J7.2, R14.1
unnamed: J14.2, R36.1
unnamed: J15.2, RV3.1
unnamed: J16.1, R35.1
PWM_FAN: J19.4, J20.4, R5.2
SHUNT1+: C20.2, Q2.3, R29.1, U3.5, U7.2
SHUNT2+: C21.2, Q4.3, R30.1, U3.4, U7.6
SHUNT3+: C22.2, Q6.3, R31.1, U3.7, U8.2
SHUNT4+: C23.2, Q8.3, R32.1, U3.6, U8.6
